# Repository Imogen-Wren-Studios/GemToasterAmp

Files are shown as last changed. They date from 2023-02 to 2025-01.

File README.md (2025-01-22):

# GemToasterAmp
 9v to 12v Battery Powered Amp

 _LM386 Based power amp with JFET Preamp_

 - Quality of sound highly dependent on speaker & cab combo.
 
 ## 3D Model
 #### Iso
  
 #### Underside
 
 #### Topside
 

 ## PCB Layout
 

 ## Schematic
 
 

 ### JFET Selection
 
 _I thought there were some notes on this but I can't find them, the only other thing I had read says "Anything Goes". They used cheapo out of spec parts and they worked._
 
### Other Parts slection

Some parts can be more difficult to find or I just didnt have them in stock for my test build, so these are the values I used in my *working* build:
 
 3.9k Resistors - 15k in parallel with 5.1k
 4.3k Resistors - 15k in  parallel  with 6.2k

470n Capacitor - 390n Could put an additional 100n in parallel to get closer to marked value

15n Capacitor - 22n

## Revision 0 Issues:
- Power Amp control is backwards, but this control isnt that useable, on the origional project this was replaced with a trimpot anyway, so suggest mounting it back to front for a "set and forget" control, or replace with fixed value resistor.
   - Could also look into cutting traces between 2 and 3 - TODO

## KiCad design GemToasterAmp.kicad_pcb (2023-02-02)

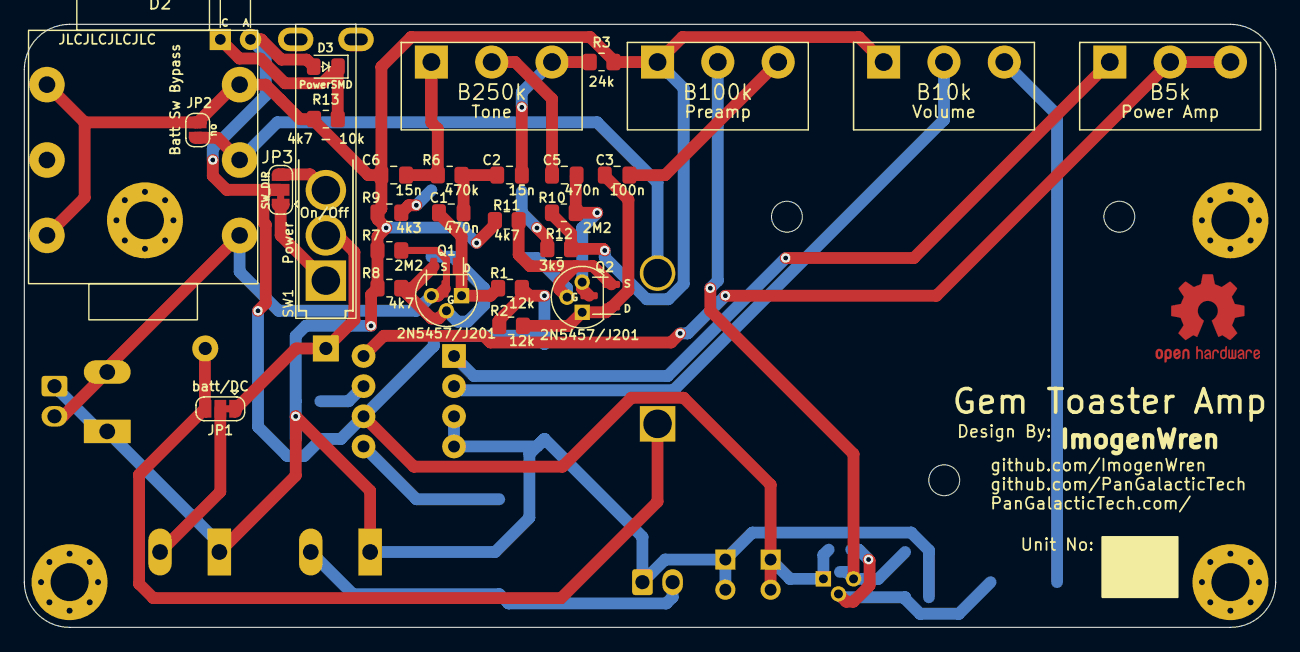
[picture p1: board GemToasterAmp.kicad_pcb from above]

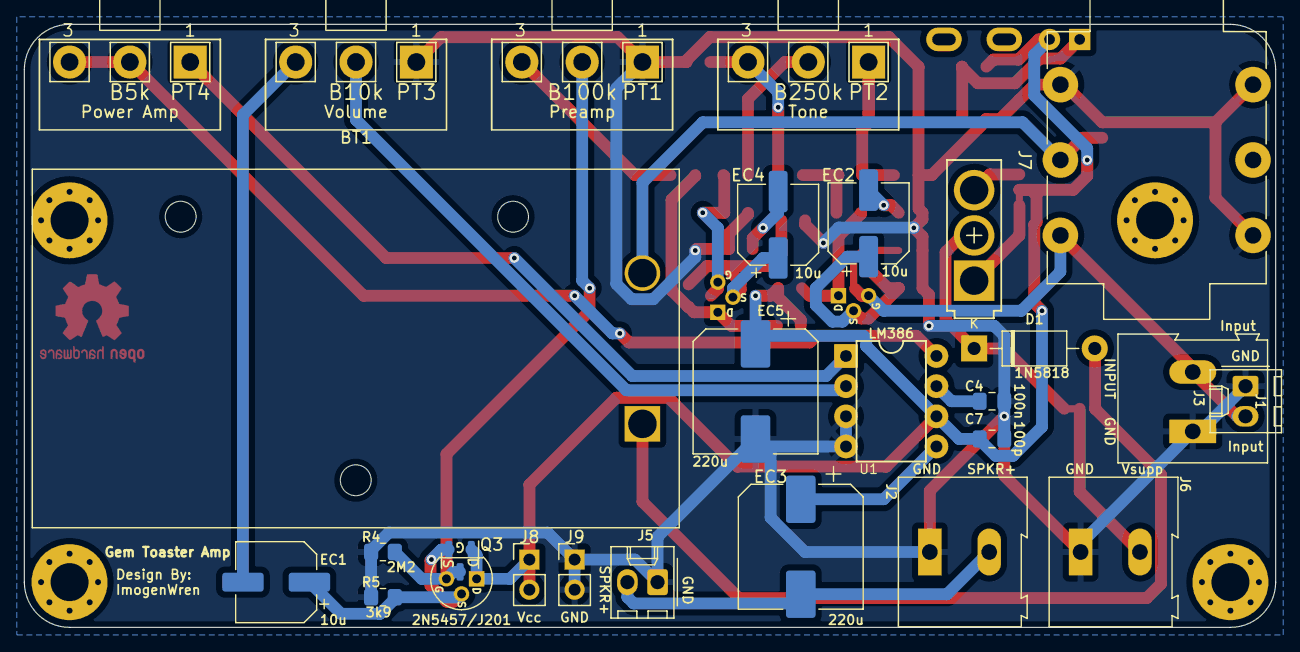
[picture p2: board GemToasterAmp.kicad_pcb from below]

Board: 2 copper layers, 105.4 x 50.8 mm, 49 parts (25 on the bottom side), 31 nets.

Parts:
BT1: 9v Battery; BatteryHolder_Eagle_12BH611-GR
C1, C5: 470n; C_0805_2012Metric_Pad1.18x1.45mm_HandSolder
C2, C6: 15n; C_0805_2012Metric_Pad1.18x1.45mm_HandSolder
C3, C4: 100n; C_0805_2012Metric_Pad1.18x1.45mm_HandSolder
C7: 100p; C_0805_2012Metric_Pad1.18x1.45mm_HandSolder
D1: 1N5818; D_DO-41_SOD81_P10.16mm_Horizontal
D2: PowerTH; LED_D5.0mm_Flat
D3: PowerSMD; LED_0805_2012Metric_Pad1.15x1.40mm_HandSolder
EC1, EC2, EC4: 10u; CP_Elec_6.3x5.9
EC3, EC5: 220u; CP_Elec_10x10
J1: Input; TerminalBlock_Altech_AK300-2_P5.00mm
J2: Speaker(2-8 ohm); TerminalBlock_Altech_AK300-2_P5.00mm
J3: Input; Molex_KK-254_AE-6410-02A_1x02_P2.54mm_Vertical_copy
J5: Speaker; Molex_KK-254_AE-6410-02A_1x02_P2.54mm_Vertical_copy
J6: Power; TerminalBlock_Altech_AK300-2_P5.00mm
J7: AudioJack3_Switch; Jack_6.35mm_Neutrik_NMJ6HFD2_Horizontal
J8: Vcc; PinHeader_1x02_P2.54mm_Vertical
J9: GND; PinHeader_1x02_P2.54mm_Vertical
JP1: batt/DC; SolderJumper-3_P1.3mm_Bridged12_RoundedPad1.0x1.5mm
JP2: Batt Sw Bypass; SolderJumper-2_P1.3mm_Open_RoundedPad1.0x1.5mm
JP3: SW_DIR; SolderJumper-3_P1.3mm_Bridged12_RoundedPad1.0x1.5mm
PT1: B100k; 16MM_AngleMount
PT2: B250k; 16MM_AngleMount
PT3: B10k; 16MM_AngleMount
PT4: B5k; 16MM_AngleMount
Q1, Q2, Q3: 2N5457/J201; JFET Dual Foot
R1, R2: 12k; Resistor_0805_2012_handsolder
R3: 24k; Resistor_0805_2012_handsolder
R4, R7, R10: 2M2; Resistor_0805_2012_handsolder
R5, R12: 3k9; Resistor_0805_2012_handsolder
R6: 470k; Resistor_0805_2012_handsolder
R8, R11: 4k7; Resistor_0805_2012_handsolder
R9: 4k3; Resistor_0805_2012_handsolder
R13: 4k7 - 10k; Resistor_0805_2012_handsolder
SW1: On/Off; SPDT-100SP4T1-Right-Angle
U1: LM386; DIL8

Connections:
+BATT: BT1.1 (+), D1.2 (A), JP1.3 (B)
-BATT: BT1.2 (-), J7.R, JP2.2 (B)
/INPUT: J1.2, J3.2, J7.T, Q1.3 (G), R7.1
/SPKR+: EC3.2, J2.2, J5.2
/Vsupp: J6.2, JP1.2 (C)
/power_in: D1.1 (K), JP1.1 (A), SW1.2 (B)
GND: C4.1, C6.2, C7.2, EC5.2, J1.1, J2.1, J3.1, J5.1, J6.1, J7.S, J7.SN, J7.TN, J9.1, J9.2, JP2.1 (A), PT1.1, PT3.1, R3.2, R4.2, R5.2, R7.2, R8.2, R9.2, R10.2, R11.2, R12.2, R13.1, U1.3 (+), U1.4 (GND)
unnamed: C1.1, Q1.1 (D), R1.2
unnamed: C1.2, C2.2, R6.1
unnamed: C2.1, PT2.3, R3.1
unnamed: C3.1, Q2.1 (D), R2.2
unnamed: C3.2, PT1.3
unnamed: C4.2, U1.7 (BYPASS)
unnamed: C5.1, PT2.2
unnamed: C5.2, Q2.3 (G), R10.1
unnamed: C6.1, PT2.1, R6.2
unnamed: D2.1 (K), D3.1 (K), R13.2
unnamed: EC1.1, Q3.2 (S), R5.1
unnamed: EC1.2, PT3.3
unnamed: EC2.1, Q1.2 (S), R8.1
unnamed: EC2.2, R9.1
unnamed: EC3.1, U1.5
unnamed: EC4.1, Q2.2 (S), R11.1
unnamed: EC4.2, R12.1
unnamed: PT1.2, Q3.3 (G), R4.1
unnamed: PT3.2, U1.2 (-)
unnamed: PT4.1, U1.1 (GAIN)
unnamed: PT4.2, PT4.3, U1.8 (GAIN)
unnamed: JP3.1 (A), SW1.1 (A)
unnamed: JP3.3 (B), SW1.3 (C)
VCC: C7.1, D2.2 (A), D3.2 (A), EC5.1, J8.1, J8.2, JP3.2 (C), Q3.1 (D), R1.1, R2.1, U1.6 (V+)

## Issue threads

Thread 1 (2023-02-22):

Power Amp Gain pot wired in reverse

ImogenWren, 2023-02-22:

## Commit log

2022-12-21 layout v0.1
    [GemToasterAmp.kicad_pcb, GemToasterAmp.kicad_sch]
2023-02-02 added gerbers
    [GemToasterAmp-B_Cu.gbr, GemToasterAmp-B_Mask.gbr, GemToasterAmp-B_Paste.gbr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]
